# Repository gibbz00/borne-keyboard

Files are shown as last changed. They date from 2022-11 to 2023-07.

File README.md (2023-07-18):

# Borne V1 Keyboard

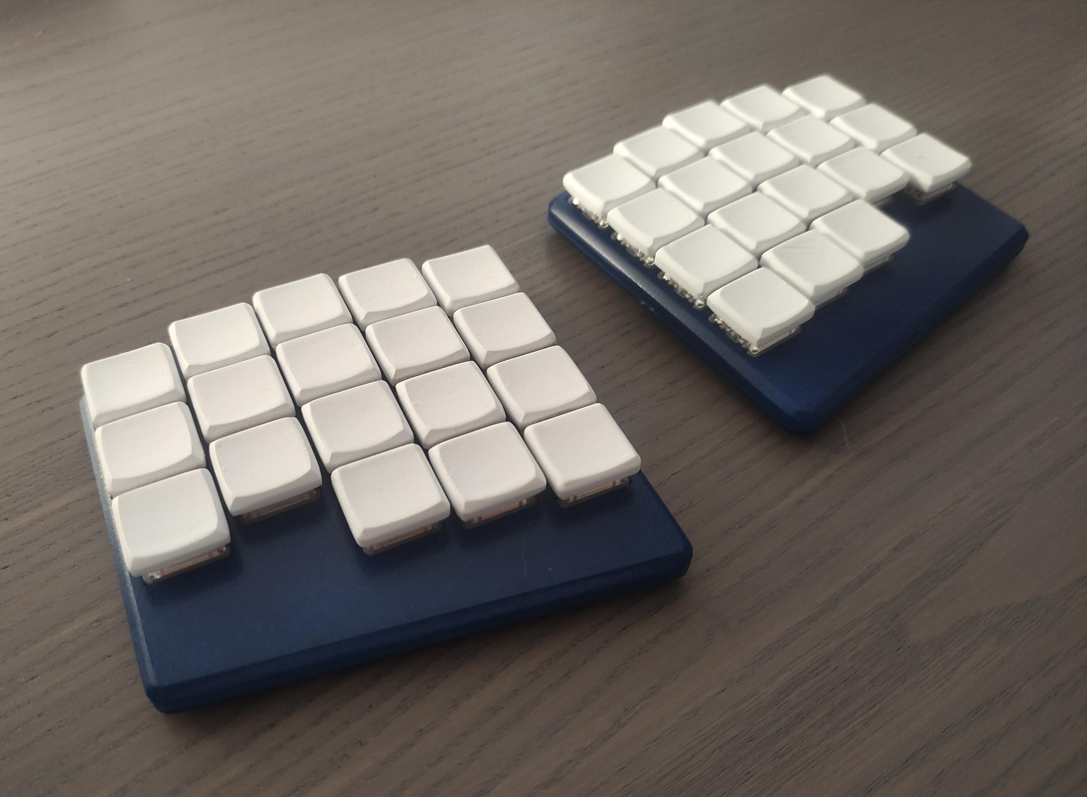
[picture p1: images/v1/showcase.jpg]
showcase image


V2 interest check is now live: https://www.reddit.com/r/mechmarket/comments/10xzn65/ic_borne_v2_a_slim_wireless_and_split_keyboard/

Source files for the Borne Keyboard; a wireless, split, 36-key, orthogonal keyboard with a comparatively large battery capacity that should last over two months.
Also of low profile at a max height of about 17 mm (0.67 in).
Ready-made ZMK and Adafruit nrf52 bootloader binaries are placed in the `firmware/builds` directory.

Currently rocking this keyboard layout: http://www.keyboard-layout-editor.com/#/gists/0e81bf405ebbc268280f0506f7d0e771

**PLEASE NOTE THAT V1 IS A WORKING PROOF OF CONCEPT. Don't copy this project mindlessly and expect everything to work out of the box. I have notes containing over 500 points of improvements or cautions when working on this project, many of which to be added as repo issues in the near future.**

Kicad 6 and its component libraries are required to properly explore the majority of electronic design files. 

https://www.kicad.org/libraries/download/

Arch users simply install `kicad-library` and `kicad-library-3d-nightly` from the official repository.

# Customizing the keymap with ZMK

Necessary ZMK know-how can be found in its official documentation or in its welcoming community discord server: 

https://zmk.dev/docs

https://zmk.dev/community/discord/invite

## Building with GitHub Actions

Allows for keymap customizations to be done without going through the hassle of installing the respective toolchains. It works by automating firmware builds on a cloud server upon repository changes.

#### Repo setup (only once)
Log in/sign up to a personal GitHub account.
Fork https://github.com/gibbz00/borne-zmk-config
#### Keymap updates
Edit `config/borne.keymap`.
Commit and push changes to your personal repo.
#### Retrieving firmware images
In the browser; navigate to "Actions".
Select the latest workflow run.
A "firmware" artifact should appear if all went well, clicking on it should start a zip download, unzip it once completed.
#### Flashing the keyboard
Only the left shield/half/side needs to be built to update the keymap.
Connect the half over USB, put it in bootloader mode (double press reset), and make sure the device storage is mounted. 
Last step is to copy over the `borne_left-borne-zmk.uf2` file to the new USB storage device and wait until the blue LED stops blinking rapidly.

## Local builds and flashing

### Preparations

The following dependencies are required to build ZMK:
* zephyr-sdk 
* python-jsonschema
* remarshal

And for the Adafruit nRF52 bootloader:
* arm-none-eabi-gcc
* python-intelhex

For Arch Linux based distributions: All packages exist in the same name on AUR, e.g:
```
yay -S --needed python-intelhex arm-none-eabi-gcc zephyr-sdk python-jsonschema remarshal 
```

Bootloader and ZMK exist as submodules in this repository. (Not yet merged upstream.)
```
git clone URL && git submodule update
```

All firmware files unique to this keyboard are found in:
```
firmware/Adafruit_nRF52_Bootloader/src/boards/borne_keyboard/
firmware/zmk/app/boards/arm/borne-keyboard/
firmware/zmk/app/boards/shields/borne-keyboard/
```

Those only interested in updating the keymap need not look any further than:
```
firmware/zmk/app/boards/shields/borne-keyboard/borne.keymap
```

### Building ZMK

Only the left shield/half/side needs to be built to update the keymap:
```
# in the firmware/zmk/app directory
west build -d build/left --pristine --board borne -- -DSHIELD=borne_left
```
### Flashing ZMK
Connect the half over USB, put it in bootloader mode (double press reset), and make sure the device storage is mounted. Then:
```
# still in the firmware/zmk/app directory
cp build/left/zephyr/zmk.uf2 path_to_borne_mass_storage/CURRENT.uf2
```

If necessary, change the occurrences of "left" to "right" to build the other half. 

### Adafruit nrf52 bootloader

Multiple ways of building and then flashing the boards over UART is explained in Joric's diligent write-up: https://github.com/joric/nrfmicro/wiki/Bootloader

I only got flashing with OpenOCD on the Raspberry Pi 4 to work.
The hardware specific `openocd.cfg` is found in the `firmware` directory.
Additional resources on how to flash the nrf5240 with OpenOCD and a Raspberry Pi 4 are found at: https://www.rototron.info/circuitpython-nrf52840-dongle-openocd-pi-tutorial/

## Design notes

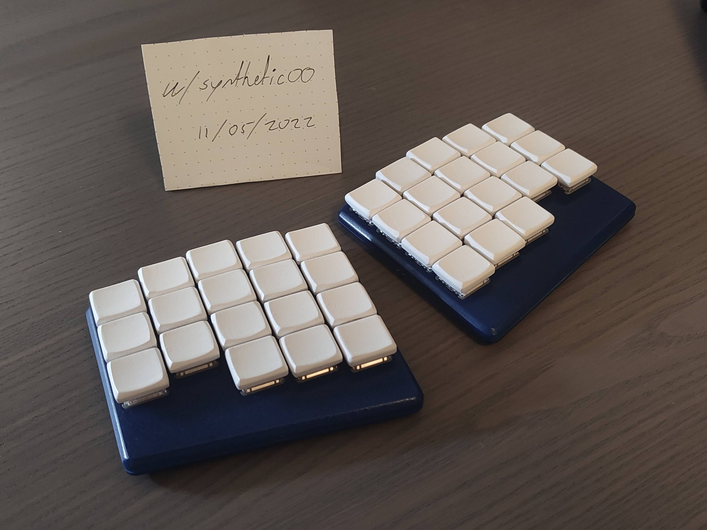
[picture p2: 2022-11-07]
images/v1/first.jpg

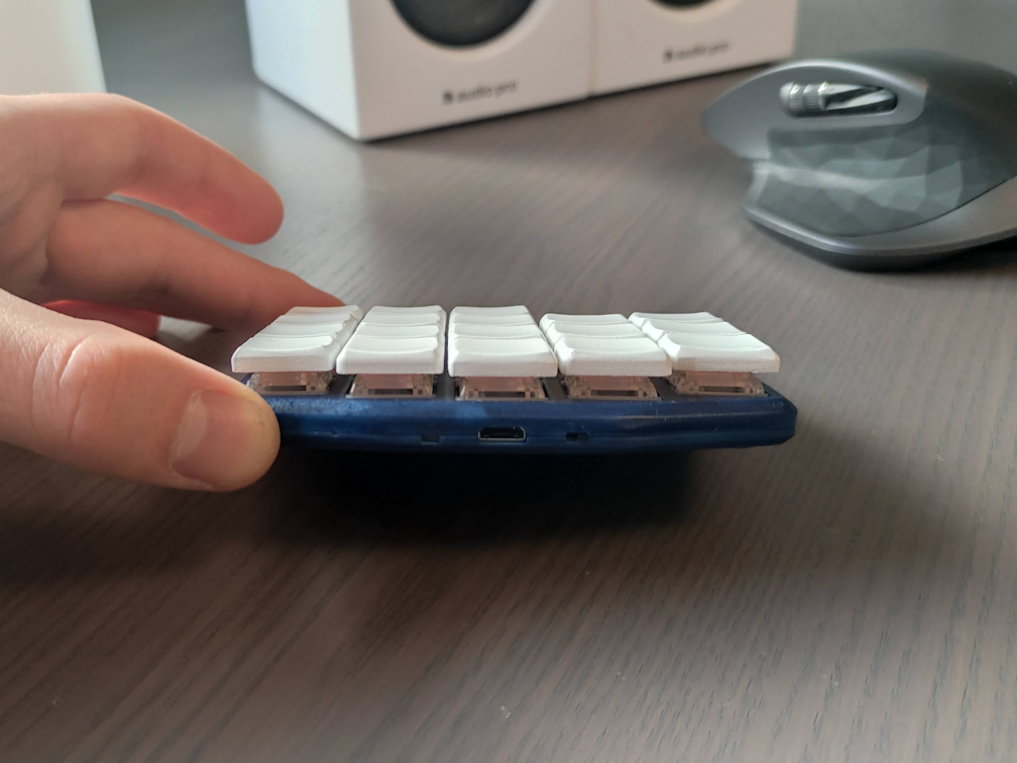
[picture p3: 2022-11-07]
images/v1/front-io.jpg

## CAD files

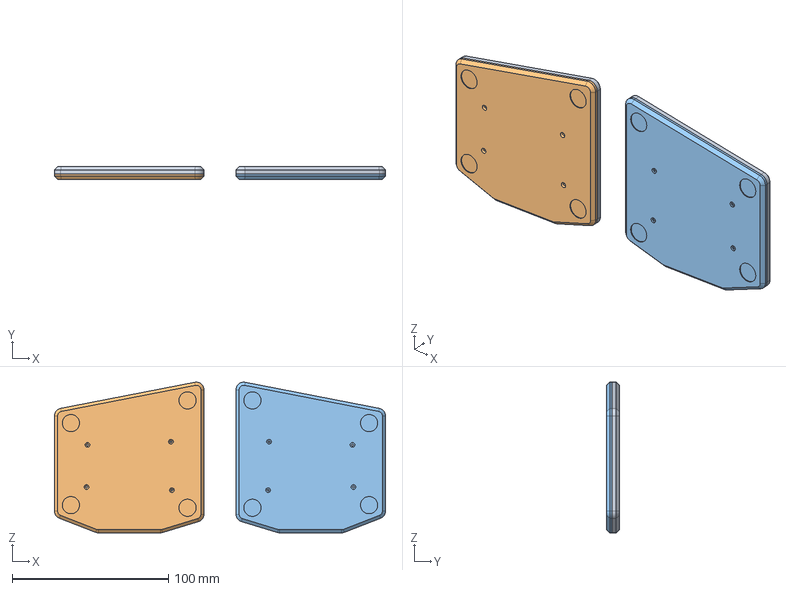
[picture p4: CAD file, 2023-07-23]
enclosure/3x5/case.stp
211.7 x 8.05 x 96.4 mm

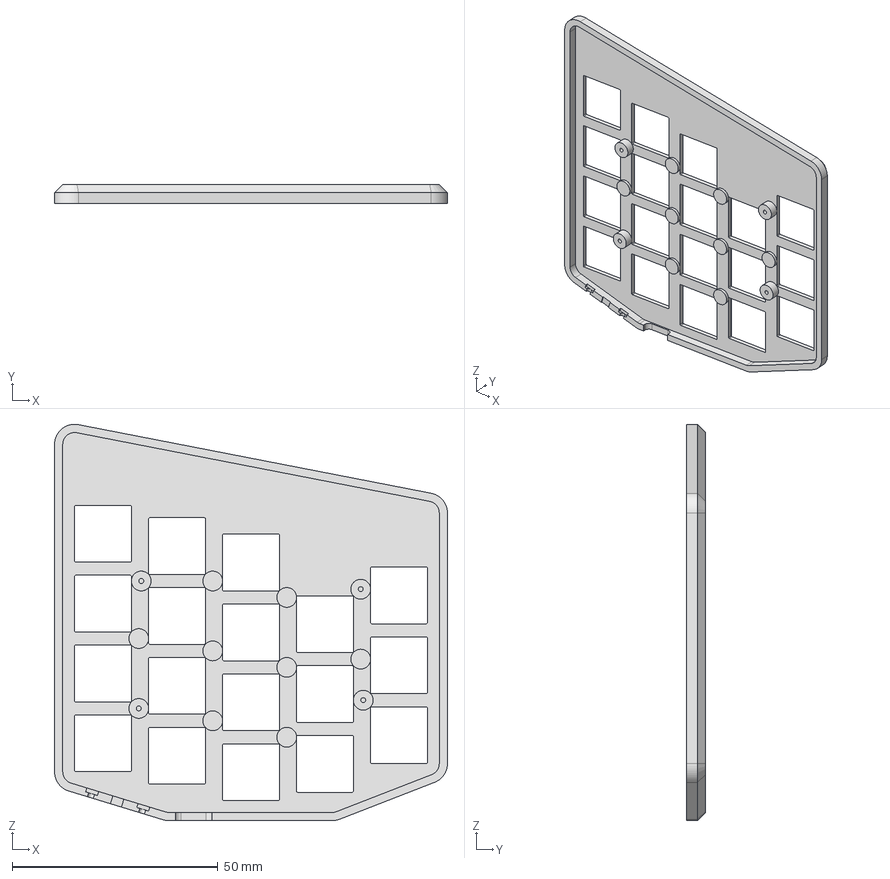
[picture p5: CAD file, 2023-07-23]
enclosure/3x5/production/right_top_3x5.stp
95.6 x 4.70 x 96.4 mm

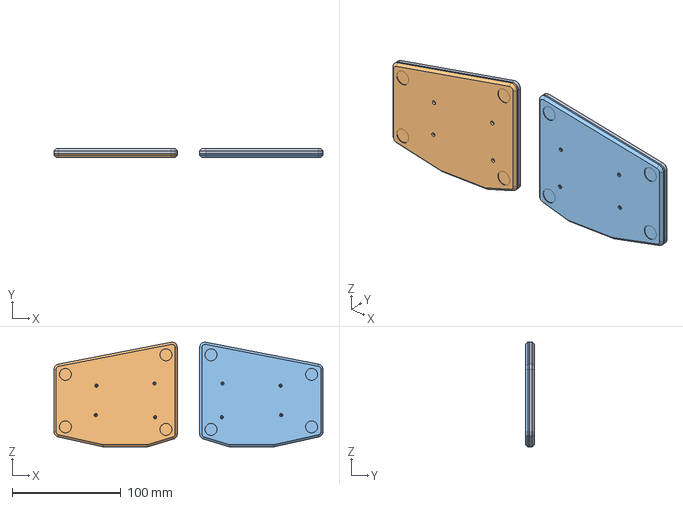
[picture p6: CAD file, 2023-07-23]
enclosure/3x6/case.stp
247.7 x 8.05 x 96.4 mm

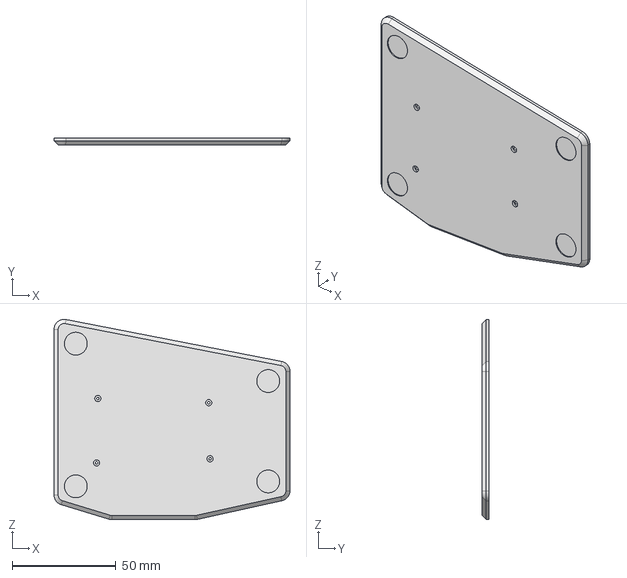
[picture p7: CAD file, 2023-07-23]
enclosure/3x6/production/right_bottom_3x6.stp
113.6 x 3.35 x 96.4 mm

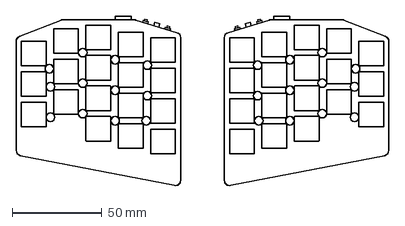
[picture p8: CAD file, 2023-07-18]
enclosure/3x5/outlines.dxf
207.7 x 94.5 mm

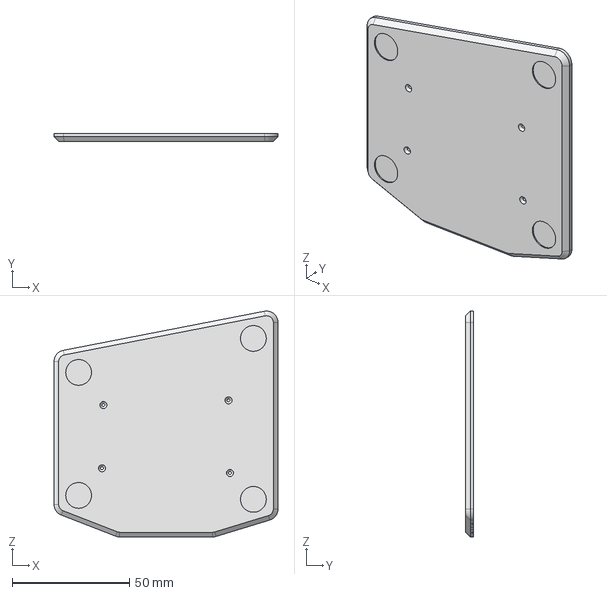
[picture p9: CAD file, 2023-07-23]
enclosure/3x5/production/left_bottom_3x5.stp
95.6 x 3.35 x 96.4 mm

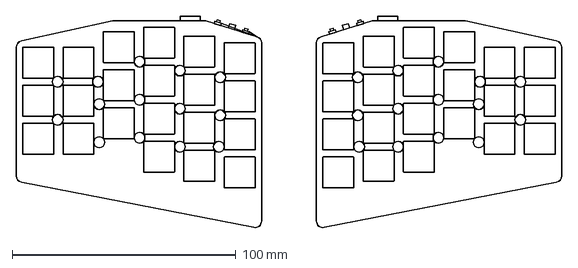
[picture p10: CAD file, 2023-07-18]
enclosure/3x6/outlines.dxf
243.7 x 94.5 mm

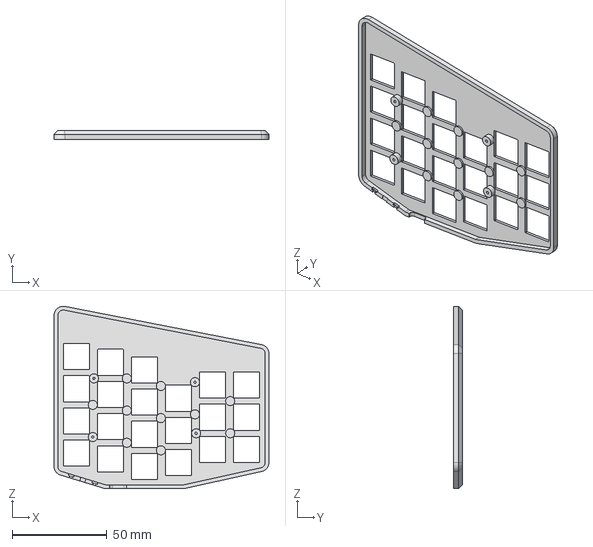
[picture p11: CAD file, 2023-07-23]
enclosure/3x6/production/right_top_3x6.stp
113.6 x 4.70 x 96.4 mm

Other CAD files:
enclosure/3x5/production/right_bottom_3x5.stp
enclosure/3x6/production/left_top_3x6.stp
enclosure/3x5/production/left_top_3x5.stp
enclosure/3x6/production/left_bottom_3x6.stp

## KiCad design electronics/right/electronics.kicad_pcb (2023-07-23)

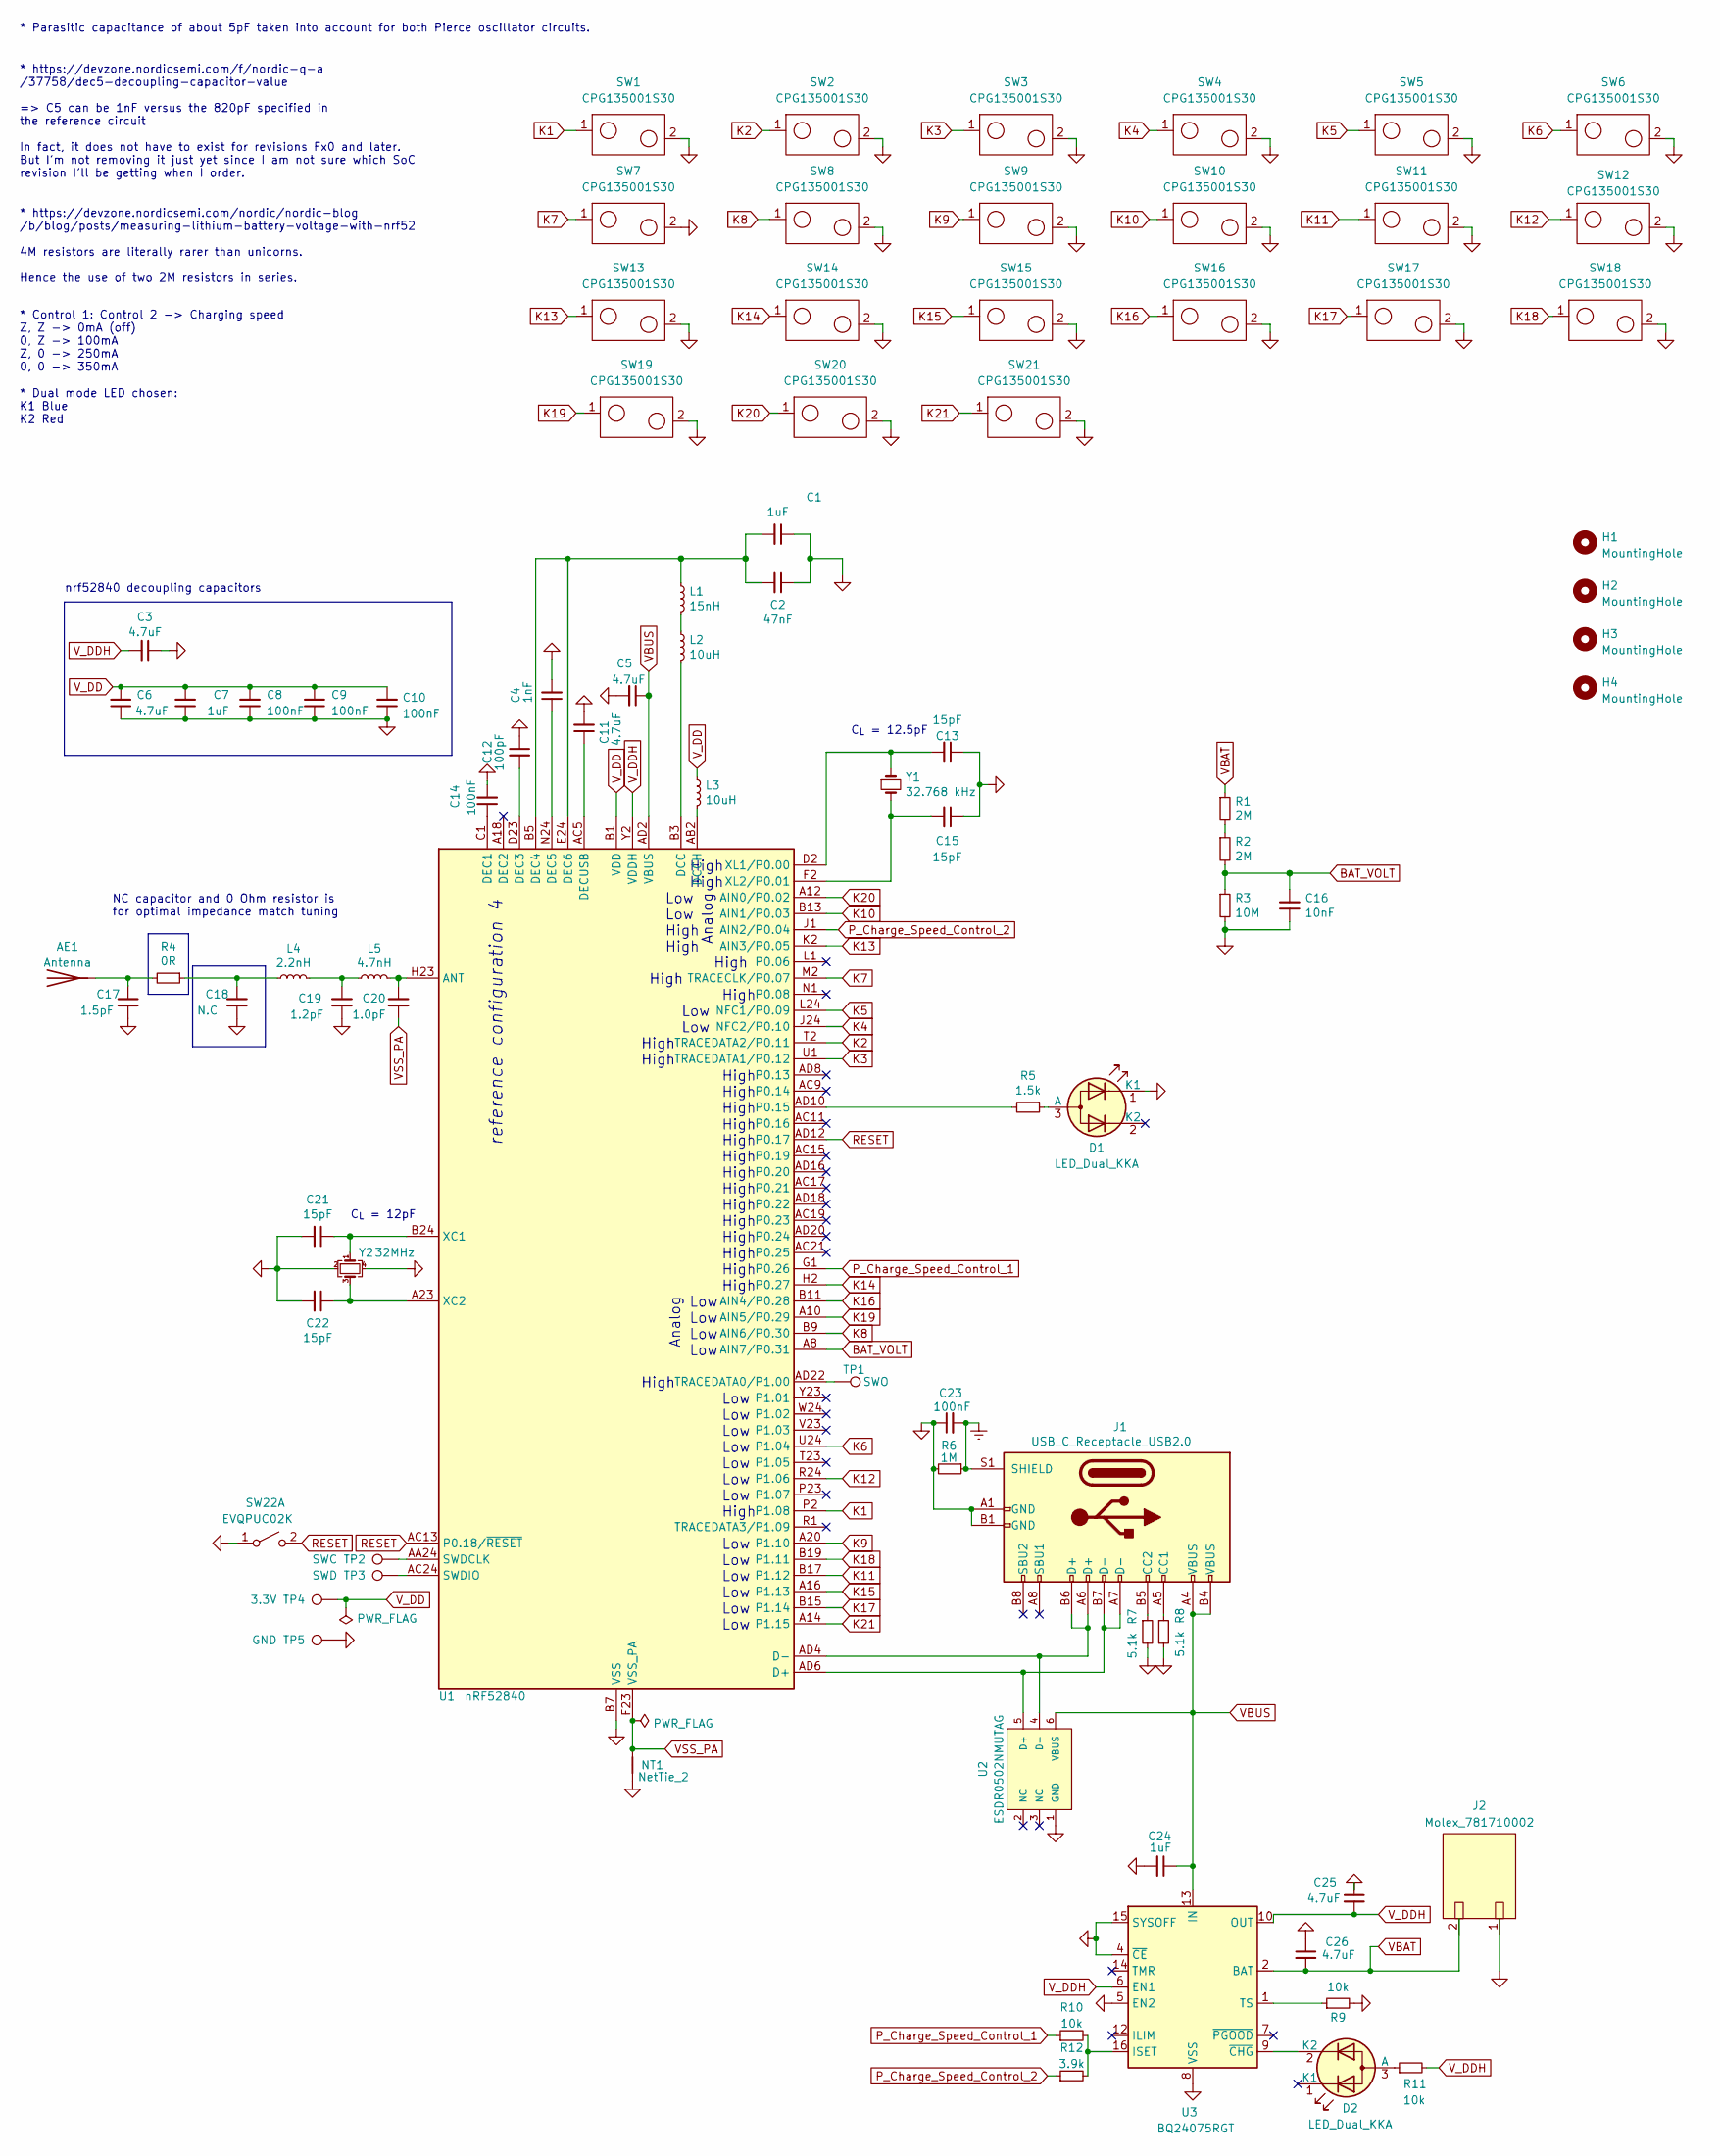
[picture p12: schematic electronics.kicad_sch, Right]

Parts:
AE1: Antenna; 2.4GHz-meander-antenna-right
C1, C7, C24: 1uF; C_0402_1005Metric; Manufacturer Part CL05A105KO5NNNC; LCSC Part C52923
C2: 47nF; C_0402_1005Metric; Manufacturer Part CL05B473KO5NNNC; LCSC Part C307434
C3, C5, C6, C11, C25, C26: 4.7uF; C_0402_1005Metric; Manufacturer Part CL05A475KP5NRNC; LCSC Part C368809
C4: 1nF; C_0402_1005Metric; Manufacturer Part CL05B104KA5NNNC; LCSC Part C1525
C8, C9, C10, C14: 100nF; C_0402_1005Metric; Manufacturer Part CL05B104KA5NNNC; LCSC Part C1525
C12: 100pF; C_0402_1005Metric; Manufacturer Part CL05C101JB5NNNC; LCSC Part C26409
C13, C15, C21, C22: 15pF; C_0402_1005Metric; Manufacturer Part CL05C150JB51PNC; LCSC Part C307341
C16: 10nF; C_0402_1005Metric; Manufacturer Part CL05B103KB5NNNC; LCSC Part C15195
C17: 1.5pF; C_0402_1005Metric; Manufacturer Part CL05C1R5CB5NNNC; LCSC Part C170150
C18: N.C; C_0402_1005Metric; Manufacturer Part CL05C010CB5NNNC; LCSC Part C371977
C19: 1.2pF; C_0402_1005Metric; Manufacturer Part CL05C010CB5NNNC; LCSC Part C371977
C20: 1.0pF; C_0402_1005Metric; Manufacturer Part CL05C010CB5NNNC; LCSC Part C371977
C23: 100nF; C_0402_1005Metric; Manufacturer Part CL05A475KP5NRNC; LCSC Part C368809
D1, D2: LED_Dual_KKA; LED-ARRAY-SMD_3P-L3.0-W2.0-L-FD; Manufacturer Part 12-22/BHR6C-A01/2C; LCSC Part C605447
H1, H2, H3, H4: MountingHole; screw-hole
J1: USB_C_Receptacle_USB2.0; USB-C-SMD_TYPE-C-31-M-13A-1; Manufacturer Part GT-USB-9014C; LCSC Part C2988367
J2: Molex_781710002; Molex_Pico-EZmate_78171-0002_1x02-1MP_P1.20mm_Vertical; Manufacturer Part 781710002; LCSC Part C505023
L1: 15nH; L_0402_1005Metric; Manufacturer Part MLG1005S15NJT000; LCSC Part C76763
L2, L3: 10uH; L_0603_1608Metric; Manufacturer Part MLF1608E100KTD00; LCSC Part C76732
L4: 2.2nH; L_0402_1005Metric; Manufacturer Part MLG1005S3N9BT000; LCSC Part C76775
L5: 4.7nH; L_0402_1005Metric; Manufacturer Part MLG1005S3N9BT000; LCSC Part C76775
NT1: NetTie_2; net-tie-2-tiny
R1, R2: 2M; R_0402_1005Metric; Manufacturer Part RC0402FR-072ML; LCSC Part C138014
R3: 10M; R_0402_1005Metric; Manufacturer Part RC0402FR-0710ML; LCSC Part C138067
R4: 0R; R_0402_1005Metric; Manufacturer Part RC0402FR-070RL; LCSC Part C106231
R5: 1.5k; R_0402_1005Metric; Manufacturer Part RC0402FR-071K5L; JLC Part C114759
R6: 1M; R_0402_1005Metric; Manufacturer Part RC0402FR-0710KL; LCSC Part C60490
R7, R8: 5.1k; R_0402_1005Metric; Manufacturer Part RC0402FR-0710KL; LCSC Part C60490
R9, R10, R11: 10k; R_0402_1005Metric; Manufacturer Part RC0402FR-0710KL; LCSC Part C60490
R12: 3.9k; R_0402_1005Metric; Manufacturer Part RC0402FR-073K9L; LCSC Part C131467
SW1, SW2, SW3, SW4, SW5, SW6, SW7, SW8, SW9, SW10, SW11, SW12, SW13, SW14, SW15, SW16, SW17, SW18, SW19, SW20, SW21: CPG135001S30; Kailh_socket_PG1350; Manufacturer Part CPG135001S30; JLC Part C5333465
SW22: EVQPUC02K; Panasonic_EVQPUL_EVQPUC; Manufacturer Part EVQPUC02K; JLC Part C79174
TP1: SWO; TestPoint_THTPad_1.5x1.5mm_Drill0.7mm
TP2: SWC; TestPoint_THTPad_1.5x1.5mm_Drill0.7mm
TP3: SWD; TestPoint_THTPad_1.5x1.5mm_Drill0.7mm
TP4: 3.3V; TestPoint_THTPad_1.5x1.5mm_Drill0.7mm
TP5: GND; TestPoint_THTPad_1.5x1.5mm_Drill0.7mm
U1: nRF52840; Nordic_AQFN-73-1EP_7x7mm_P0.5mm; Manufacturer Part NRF52840-QIAA-R; LCSC Part C1851953
U2: ESDR0502NMUTAG; Manufacturer Part ESDR0502NMUTBG; LCSC Part C327480
U3: BQ24075RGT; VQFN-16-1EP_3x3mm_P0.5mm_EP1.6x1.6mm; Manufacturer Part BQ24075RGTR; JLC Part C15464
Y1: 32.768 kHz; Crystal_SMD_2012-2Pin_2.0x1.2mm; Manufacturer Part SC20S-12.5PF20PPM; LCSC Part C97607
Y2: 32MHz; Crystal_SMD_2016-4Pin_2.0x1.6mm; Manufacturer Part Q22FA1280001800; LCSC Part C255896

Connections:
BAT_VOLT: C16.2, R2.2, R3.1, U1.A8 (AIN7/P0.31)
K1: SW1.1, U1.P2 (P1.08)
K2: SW2.1, U1.T2 (TRACEDATA2/P0.11)
K3: SW3.1, U1.U1 (TRACEDATA1/P0.12)
K4: SW4.1, U1.J24 (NFC2/P0.10)
K5: SW5.1, U1.L24 (NFC1/P0.09)
K6: SW6.1, U1.U24 (P1.04)
K7: SW7.1, U1.M2 (TRACECLK/P0.07)
K8: SW8.1, U1.B9 (AIN6/P0.30)
K9: SW9.1, U1.A20 (P1.10)
K10: SW10.1, U1.B13 (AIN1/P0.03)
K11: SW11.1, U1.B17 (P1.12)
K12: SW12.1, U1.R24 (P1.06)
K13: SW13.1, U1.K2 (AIN3/P0.05)
K14: SW14.1, U1.H2 (P0.27)
K15: SW15.1, U1.A16 (P1.13)
K16: SW16.1, U1.B11 (AIN4/P0.28)
K17: SW17.1, U1.B15 (P1.14)
K18: SW18.1, U1.B19 (P1.11)
K19: SW19.1, U1.A10 (AIN5/P0.29)
K20: SW20.1, U1.A12 (AIN0/P0.02)
K21: SW21.1, U1.A14 (P1.15)
unnamed: AE1.1 (A), C17.2, R4.2
unnamed: C18.2, L4.2, R4.1
unnamed: C19.2, L4.1, L5.1
unnamed: D1.3 (A), R5.1
unnamed: D2.3 (A), R11.1
unnamed: D2.2 (K2), U3.9 (~CHG)
unnamed: J1.A5 (CC1), R8.1
unnamed: J1.B5 (CC2), R7.1
unnamed: L1.2, L2.1
unnamed: R1.2, R2.1
unnamed: C20.2, L5.2, U1.H23 (ANT)
unnamed: J1.A7 (D-), J1.B7 (D-), U1.AD6 (D+), U2.5 (D+)
unnamed: J1.A6 (D+), J1.B6 (D+), U1.AD4 (D-), U2.4 (D-)
unnamed: L2.2, U1.B3 (DCC)
unnamed: L3.2, U1.AB2 (DCCH)
unnamed: C14.1, U1.C1 (DEC1)
unnamed: C12.2, U1.D23 (DEC3)
unnamed: C1.2, C2.2, L1.1, U1.B5 (DEC4), U1.E24 (DEC6)
unnamed: C4.1, U1.N24 (DEC5)
unnamed: C11.1, U1.AC5 (DECUSB)
unnamed: R5.2, U1.AD10 (P0.15)
unnamed: TP2.1, U1.AA24 (SWDCLK)
unnamed: TP3.1, U1.AC24 (SWDIO)
unnamed: TP1.1, U1.AD22 (TRACEDATA0/P1.00)
unnamed: C21.1, U1.B24 (XC1), Y2.1
unnamed: C22.1, U1.A23 (XC2), Y2.3
unnamed: C13.2, U1.D2 (XL1/P0.00), Y1.1
unnamed: C15.2, U1.F2 (XL2/P0.01), Y1.2
unnamed: R10.2, R12.2, U3.16 (ISET)
unnamed: R9.1, U3.1 (TS)
P_Charge_Speed_Control_1: R10.1, U1.G1 (P0.26)
P_Charge_Speed_Control_2: R12.1, U1.J1 (AIN2/P0.04)
RESET: SW22.2 (B), U1.AC13 (P0.18/~RESET), U1.AD12 (P0.17)
VBAT: C26.2, J2.2, R1.1, U3.2 (BAT), U3.3 (BAT)
VBUS: C5.1, C24.1, J1.A4 (VBUS), J1.B4 (VBUS), U1.AD2 (VBUS), U2.6 (VBUS), U3.13 (IN)
VSS_PA: C20.1, NT1.1, U1.F23 (VSS_PA)
V_DD: C6.2, C7.2, C8.2, C9.2, C10.2, L3.1, TP4.1, U1.A22 (VDD), U1.AD14 (VDD), U1.AD23 (VDD), U1.B1 (VDD), U1.W1 (VDD)
V_DDH: C3.2, C25.2, R11.2, U1.Y2 (VDDH), U3.6 (EN1), U3.10 (OUT), U3.11 (OUT)

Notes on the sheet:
High
Low
C_{L} = 12pF
* Dual mode LED chosen: K1 Blue K2 Red
* https://devzone.nordicsemi.com/nordic/nordic-blog /b/blog/posts/measuring-lithium-battery-voltage-with-nrf52 4M resistors are literally rarer than unicorns. Hence the use of two 2M resistors in series.
nrf52840 decoupling capacitors
* Parasitic capacitance of about 5pF taken into account for both Pierce oscillator circuits.
reference configuration 4
C_{L} = 12.5pF
* https://devzone.nordicsemi.com/f/nordic-q-a /37758/dec5-decoupling-capacitor-value => C5 can be 1nF versus the 820pF specified in the reference circuit In fact, it does not have to exist for revisions Fx0 and later. But I'm not removing it just yet since I am not sure which SoC revision I'll be g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
* Control 1: Control 2 -> Charging speed Z, Z -> 0mA (off) 0, Z -> 100mA Z, 0 -> 250mA 0, 0 -> 350mA
Analog
NC capacitor and 0 Ohm resistor is for optimal impedance match tuning

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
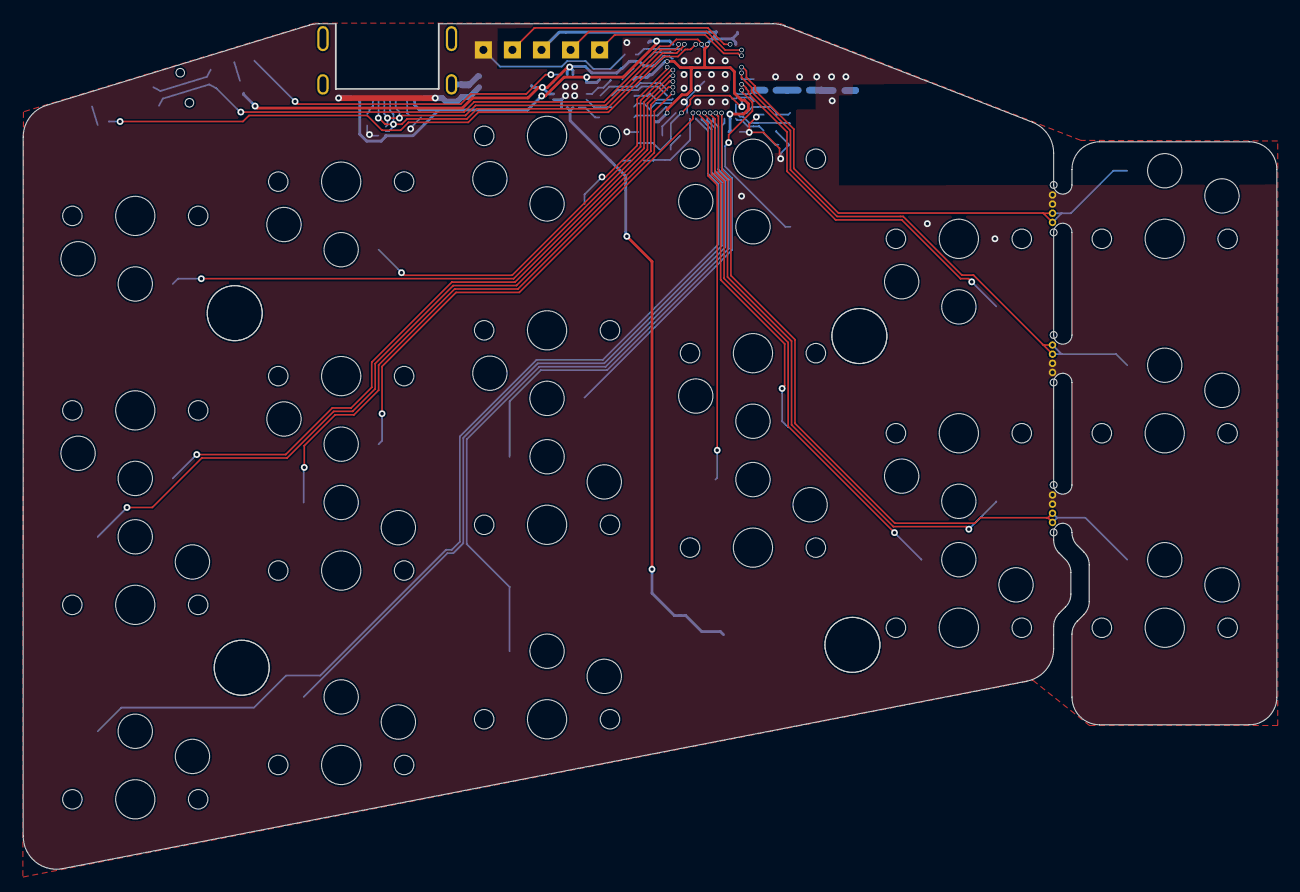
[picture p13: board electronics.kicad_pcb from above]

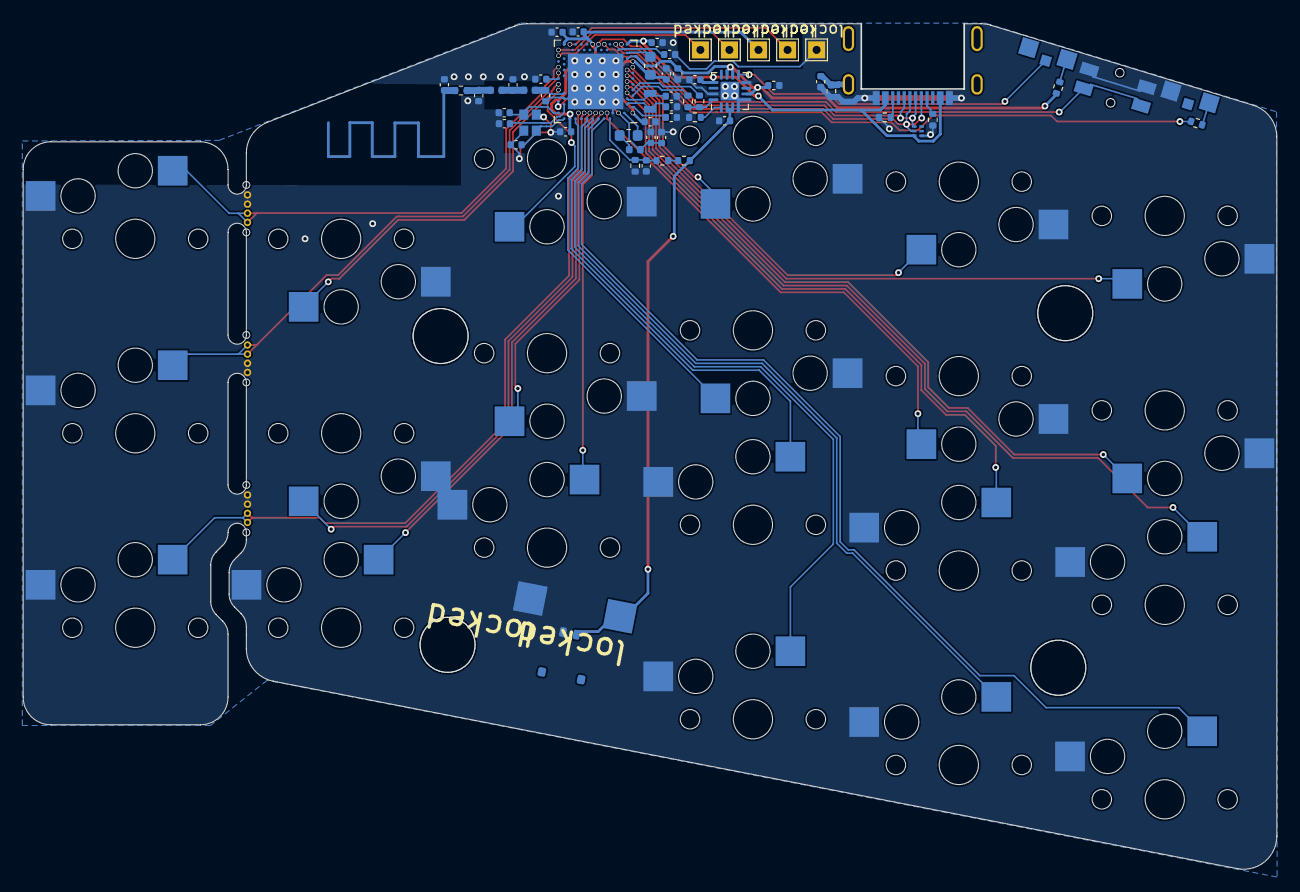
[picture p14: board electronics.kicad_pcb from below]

Board: 2 copper layers, 109.6 x 73.9 mm, 88 parts (81 on the bottom side), 62 nets.

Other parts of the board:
mouse-bite-5mm-slot, mouse-bite-5mm-slot#2, mouse-bite-5mm-slot#3: VAL**; pcb-way-single-mouse-bites-plated

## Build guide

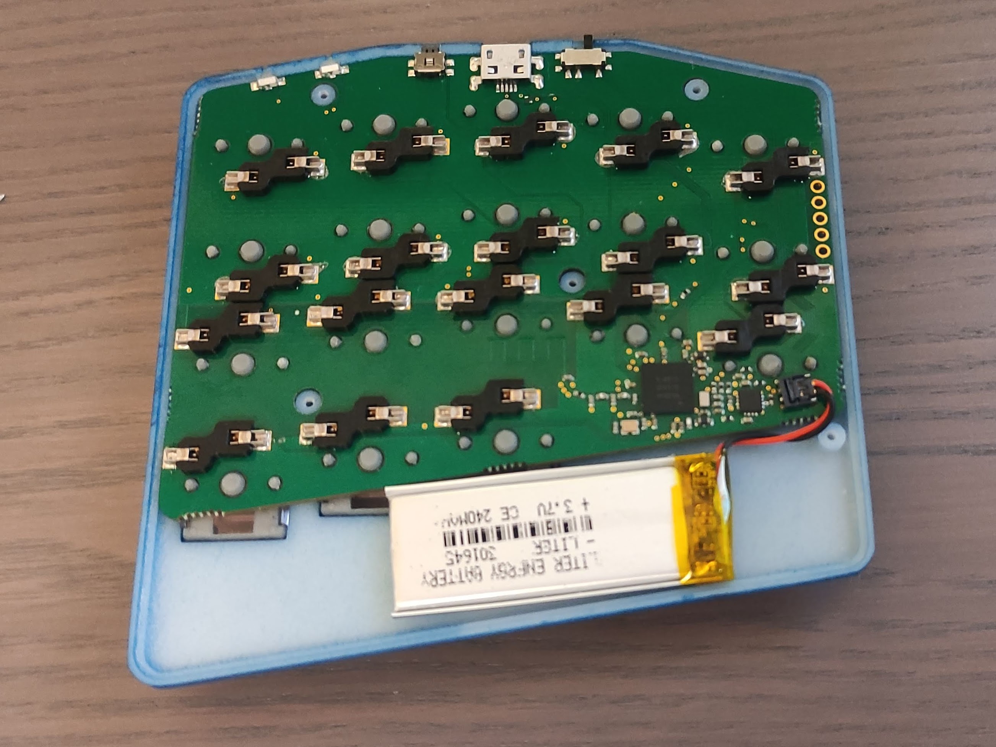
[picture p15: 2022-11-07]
images/v1/assembled.jpg

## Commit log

2022-11-06 v1 launch
    [assembly.stp, bottom-left.stp, bottom-right.stp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]
2023-07-18 Publish v2
    [assembly.stp, bom_v1.csv, bottom-left.stp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]
2023-07-19 Extend ground plane fill.
    [electronics.kicad_pcb]
2023-07-19 Mouse bite clearance accomodation.
    [electronics.kicad_pcb]
2023-07-21 Remove old bom file.
    [bom_v1.csv]
2023-07-21 Component metadata updates:
    * Use official footprints for 0402 caps and resistors.
    * Use correct JLC and LCSC part numbers for the choc switches.
    [electronics.kicad_sch]
2023-07-21 Value update for battery connector and reset switch.
    [electronics.kicad_sch]
2023-07-21 BOM value updates:
    USB C Receptable
    Molex connector.
    [electronics.kicad_sch]
2023-07-21 Add JLC Part number to LEDs
    [electronics.kicad_sch]
2023-07-21 Use official symbol for charging IC.
    [electronics.kicad_sch]
2023-07-21 Remove unused battery switch design files.
2023-07-22 electronics/right: Fix schema and PCB references parity.
    [electronics.kicad_pcb, electronics.kicad_sch]
2023-07-22 electronics/left: Fix schema and PCB references parity.
    [electronics.kicad_pcb, electronics.kicad_sch]
2023-07-22 Remove footprint placement silkscreen lines.
    [electronics.kicad_pcb]
2023-07-23 electronics/right: Add missing battery pads.
    [electronics.kicad_pcb]
2023-07-23 Make sure left and right halves produce the same BOM.
    [electronics.kicad_pcb, electronics.kicad_sch]
2023-07-23 Enclosure: New screw dimensions.
    [case.stp, left-bottom.stp, left-top.stp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]
2023-07-24 Rename stp files such that 3x5 and 3x6 can be differentiated by name.
    [left_bottom_3x5.stp, left_bottom_3x6.stp, left_top_3x5.stp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]
2023-08-12 Fix incorrect manufacturer part numbers.
    [electronics.kicad_sch]
